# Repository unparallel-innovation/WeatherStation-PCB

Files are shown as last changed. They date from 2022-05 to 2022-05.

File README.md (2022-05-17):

[][cc-by-nc-sa]

This work is licensed under a
[Creative Commons Attribution-NonCommercial-ShareAlike 4.0 International License][cc-by-nc-sa].

[][cc-by-nc-sa]

[cc-by-nc-sa]: http://creativecommons.org/licenses/by-nc-sa/4.0/
[cc-by-nc-sa-image]: https://licensebuttons.net/l/by-nc-sa/4.0/88x31.png
[cc-by-nc-sa-shield]: https://img.shields.io/badge/License-CC%20BY--NC--SA%204.0-lightgrey.svg

# Unparallel Weather Station PCB

The Weather Station PCB is a board that together with, Software and 3D case allows anyone to build their low-cost weather station. The Weather Station PCB was made open source, so we are sharing in this repository the custom PCB design (Eagle and Gerbers files) and other information, as the BOM and item lists. The software for the weather station is also open-source and can be used as is, or freely customized to meet your own needs and requirements. A model for printing a 3D case for your weather station is also provided (both in other repositories).  

WeatherStation_3D_2202

The Weather Station PCB using low-cost hardware and a LoPy4 board. The LoPy4 board is equipped with several connectivity options (e.g. Sigfox, LoRa, Wi-Fi and Bluetooth). Currently, the weather station uses Sigfox and/or Wi-Fi to send the data to the cloud, however, the software can be extended to support other connectivity options. A Grafana dashboard is then used to display the historical weather data that is stored on the cloud.

The weather station uses an external sensor (AM2315) for reading temperature and relative humidity, a weather meter kit (SEN-15901) for wind speed, wind direction and precipitation. The weather station is powered from a Li-Ion battery that is charged with a photovoltaic panel which is also used to measure solar radiation. Due to the system’s low-power operation and solar energy harvesting features, it is energy autonomous and can be deployed in remote places.

Note: the custom Weather Station PCB may be ordered via [PCBWay shared project link](https://www.pcbway.com/project/shareproject/Unparallel_Weather_Station_PCB.html).

#### Measured parameters:
*	Temperature (ºC)
*	Relative Humidity (%)
*	Rainfall (mm/h)
*	Wind Speed (km/h)
*	Wind Gust Speed (km/h)
*	Wind Direction (degrees)
*	Wind Gust Direction (degrees)
*	Solar Radiation (W/m2)
*	Battery Voltage (V)

#### Components:
*	[LoPy 4.0](https://pycom.io/product/lopy4/)
* [Unparallel WeatherStation PCB](https://www.pcbway.com/project/shareproject/Unparallel_Weather_Station_PCB.html)
*	[Unparallel WeatherStation Enclosure](https://github.com/unparallel-innovation/WeatherStation-Enclosure)
*	[Encased I2C Temperature/Humidity Sensor - AM2315](https://www.adafruit.com/product/1293)
*	[Weather Meter Kit - SEN-15901](https://www.sparkfun.com/products/15901)
*	[Li-Ion battery (3.65V - 8000mAh)](https://www.tme.eu/en/details/cl-18650-29e_1s3p/rechargeable-batteries/cellevia-batteries/)
*	[Solar Panel (2.5W - 116x160mm)](https://www.seeedstudio.com/2-5W-Solar-Panel-116X160.html)
*	[Sigfox Antenna Kit (868MHz)](https://pycom.io/product/lora-868mhz-915mhz-sigfox-antenna-kit/)
* [Expansion Board 3.0](https://pycom.io/product/expansion-board-3-0/)

## Related Repositories:
*	[Unparallel WeatherStation Enclosure](https://github.com/unparallel-innovation/WeatherStation-Enclosure)
*	[Unparallel WeatherStation Documentation](https://github.com/unparallel-innovation/WeatherStation-Documentation)
*	[Unparallel WeatherStation Software](https://github.com/unparallel-innovation/WeatherStation-Software)
*	[Unparallel WeatherStation Connector](https://github.com/unparallel-innovation/WeatherStation-Connector)

###### This work was done in the context of SmartAgriHubs Research Project, which has received funding from the European Union’s Horizon 2020 research and innovation programme under grant agreement No 818182

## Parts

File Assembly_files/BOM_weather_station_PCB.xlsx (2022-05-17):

Item # | Schematic Reference | Qty per brd | Value | Package | Manufacturer Part Number (MPN) | MFR | Description | Type | Notes
1 | C1 C2 | 2 | 10n | C0603 | 885012206089 | Wurth Elektronik | CAP MLCC - SMD/SMT WCAP-CSGP 0.01uF 0603 10% 50V | SMD
2 | C3 | 1 | 220n | C0603 | CC0603KRX7R7BB224 | YAGEO | CAP MLCC - SMD/SMT 16V 0.22uF X7R 0603 10% | SMD
3 | C4 C9 C13 | 3 | 100n | C0603 | CC0603KRX7R8BB104 | YAGEO | CAP MLCC - SMD/SMT 0603 25V 0.1uF X7R 0603 10% | SMD
4 | C5 C6 C7 C10 | 4 | 1u | C0805 | C0805C105K3RACTU | KEMET | CAP MLCC - SMD/SMT 25V 1uF X7R 0805 10% | SMD
5 | C8 | 1 | 4u7 | C0805 | GRM21BZ7YA475KE15L | Murata | CAP MLCC - SMD/SMT 35V 4.7uF X7R 0805 10% | SMD | Alternative: C0805C475K4RACAUTO
6 | CN1 | 1 | S2B-PH-SM4 | JST_2PIN-SMT-RA | S2B-PH-SM4-TB(LF)(SN) | JST | SOCKET Male; PH; 2mm; PIN: 2; SMT | SMD | Alternative: B2B-PH-SM4-TB (pins aligned to the outside of the board)
7 | D1 D2 D4 D5 D6 D7 D8 D12 | 8 | SS14L | SUB_SMA | SS14L | Taiwan Semiconductor | Schottky Rectifiers 1A 40V Sub SMA-2 | SMD
8 | D11 Or D9 | 1 | CZRB5339B-HF | DO-214AA-2 OR DO-15-2 | CZRB5339B-HF Or 1N5339B-TP | Comchip Technology Or Micro Commercial Components (MCC) | Zener Diodes 5W 5.6V SMB DO-214AA-2 Or Zener Diodes 5.0W 5.6V 1uA 865mA 13.4A DO-15-2 | SMD Or THT | If has problem to buy the D11 item, can you buy the D9 item D11 Alternative: SMBJ5339B-TP
9 | D3 D10 | 2 | RFN2LAM4STFTR | SOD-128 | RFN2LAM4STFTR | ROHM Semiconductor | Diodes 400V VR 1.5A IO SOD-128; PMDTM | SMD
10 | F1 F2 | 2 | 0ZCK0075FF2E | PTC-0805 | 0ZCK0075FF2E | Bel | Resettable Fuses - PPTC Hold current 750 mA 0805 | SMD
11 | J1 J2 | 2 | RJ11 | RJ11-6 | 95501-2661 | Molex | Ethernet Connectors RA 6/6 RJ12 LOW PROFILE THT | THT | Alternative: 54601-906WPLF
12 | JP3 JP4 | 2 | 14POS 2.54mm | LOPY4_SHIELD | DS1023-1*14S21 | CONNFLY | CONN Female; PIN: 14; straight; 2.54mm; THT; 1x14; 3A | THT
13 | JP5 | 1 | 6POS 2.54mm | PINHD-1X6 | DS1023-1*6S21 | CONNFLY | CONN Female; PIN: 6; straight; 2.54mm; THT; 1x6; 3A | THT
14 | JP7 JP8 JP9 JP10 | 4 | Block 1x2 5mm | W237-102 | DG300-5.0-2P12 | DEGSON ELECTRONICS | PCB terminal block; angled 90°; 5mm; ways: 2; on PCBs; 2.5mm2; 24A | THT | Alternative: EBBA-02-C-SS-BU
15 | LED1 | 1 | Green_LED | LED0805 | LG R971-KN-1 | Osram Opto Semiconductor | Standard LEDs - SMD 0805 Green, 570nm 26mcd, 20mA | SMD | Cathode has a mark (".") Alternative: LTST-C170KGKT
16 | Q1 Q3 Q9 | 3 | SI2333DDS | SOT-23-3 | SI2333DDS-T1-GE3 | Vishay | Transistor: P-MOSFET; unipolar; -12V; -5.2A; Idm: -20A; 1.1W; SOT-23-3 | SMD | Alternative: DMG2305UX
17 | Q2 Q5 Q6 | 3 | BSS138 | SOT-23-3 | BSS138-7-F | Diodes Incorporated | MOSFET 300mW 50V DSS SOT-23-3 N-channel | SMD
18 | R1 R2 R3 R5 R6 R7 R18 | 7 | 1k | R0603 | CR0603-FX-1001ELF | Bourns | RES Thick Film Resistors - SMD 0603 1K 1% 1/10W | SMD
19 | R10 | 1 | 200m | R0805 | RL1220S-R20-F | Susumu | RES Current Sense Resistors - SMD 0805 1/3W 0.20ohm 1% | SMD | Alternative: KDV08FR200ET
20 | R11 R12 | 2 | 10R | R0603 | CRCW060310R0FKEAC | Vishay | RES Thick Film Resistors - SMD 0603 1/10Watt 10ohms 1% Commercial Use | SMD
21 | R13 R22 R27 R33 | 4 | 47k | R0603 | RC0603FR-0747KL | YAGEO | RES Thick Film Resistors - SMD 47 kOhms 100mW 0603 1% | SMD
22 | R14 R15 R26 R39 | 4 | 10k | R0603 | CR0603-FX-1002ELF | Bourns | RES Thick Film Resistors - SMD 0603 10K 1% 1/10W | SMD
23 | R16 R37 R40 | 3 | 0R | R0603 | CR0603-J/-000ELF | Bourns | RES Thick Film Resistors - SMD 0 ohm Jumper 0603 | SMD | Soldering RES jumper (or Shunt)
24 | R19 R20 R30 | 3 | 100k | R0603 | RC0603FR-07100KL | YAGEO | RES Thick Film Resistors - SMD 0603 100 kOhms 100mW 0603 1% | SMD
25 | R23 R25 R36 | 3 | 200k | R0603 | CRCW0603200KFKEAC | Vishay | RES Thick Film Resistors - SMD 0603 1/10Watt 200Kohms 1% | SMD
26 | R29 | 1 | 2k74 | R0603 | RC0603FR-132K74L | YAGEO | RES Thick Film Resistors - SMD 0603 2.74kOhms 1/10W 0603 1% | SMD
27 | R4 | 1 | 4k7 | R0603 | RC0603FR-074K7L | YAGEO | RES Thick Film Resistors - SMD 4.7 kOhms 100mW 0603 1% | SMD
28 | R8 | 1 | 22k | R0603 | RC0603FR-0722KL | YAGEO | RES Thick Film Resistors - SMD 22 kOhms 100mW 0603 1% | SMD
29 | R9 R24 | 2 | 499k | R0603 | CR0603-FX-4993ELF | Bourns | RES Thick Film Resistors - SMD 499K ohm 0603 1% | SMD
30 | U1 | 1 | INA219BIDCN | SOT-23-8 | INA219BIDCN | Texas Instruments | IC Current & Power Monitors & Regulators 0-Drift,Bi-dir Current/Pwr Monitor SOT-23-8 | SMD
31 | U2 | 1 | MCP73831T | SOT23-5 | MCP73831T-2ACI/OT | Microchip | IC Battery Management Charge LI-ION 1CEL | SMD
32 | U3 | 1 | SN74AUP2G14DCKR | SC70-6 | SN74AUP2G14DCKR | Texas Instruments | IC Inverters Lo-Pwr Dual Schmitt- Trigger Inverter SC70-6 | SMD

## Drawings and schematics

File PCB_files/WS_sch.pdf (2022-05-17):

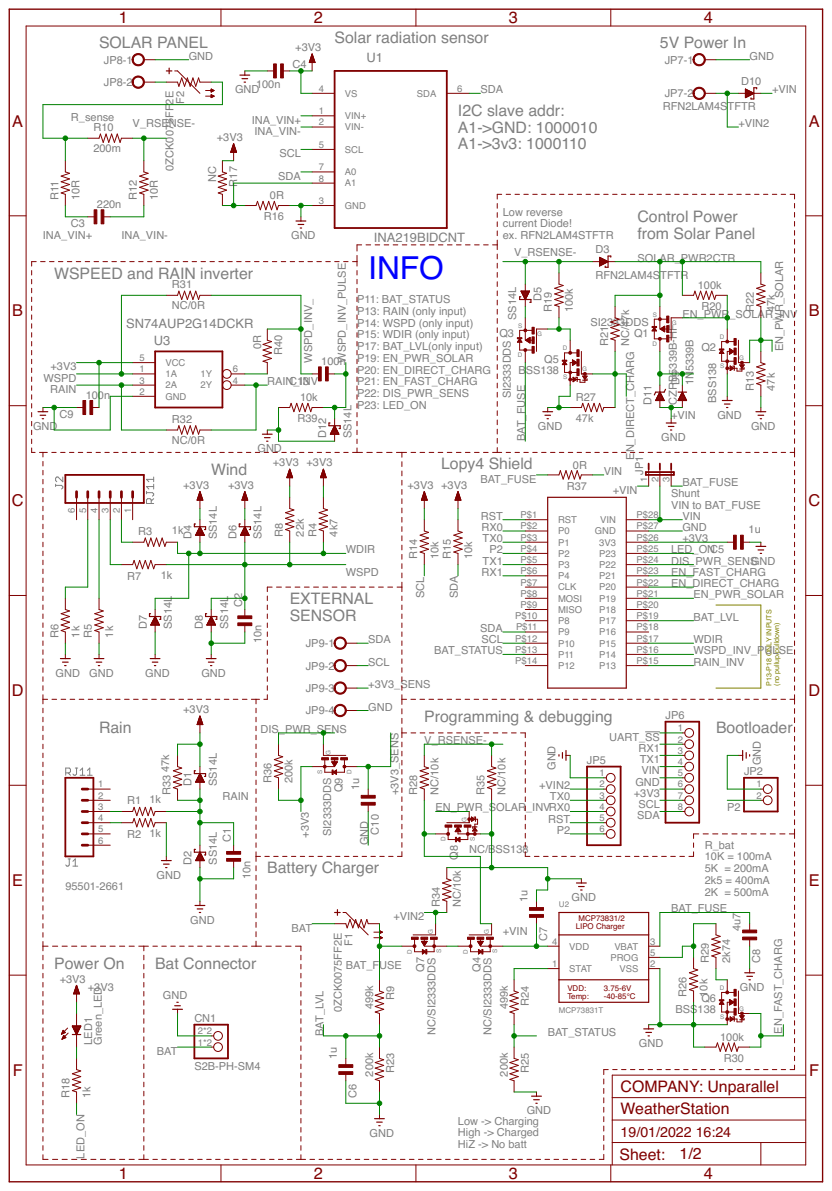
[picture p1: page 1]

WSPEED and RAIN inverter

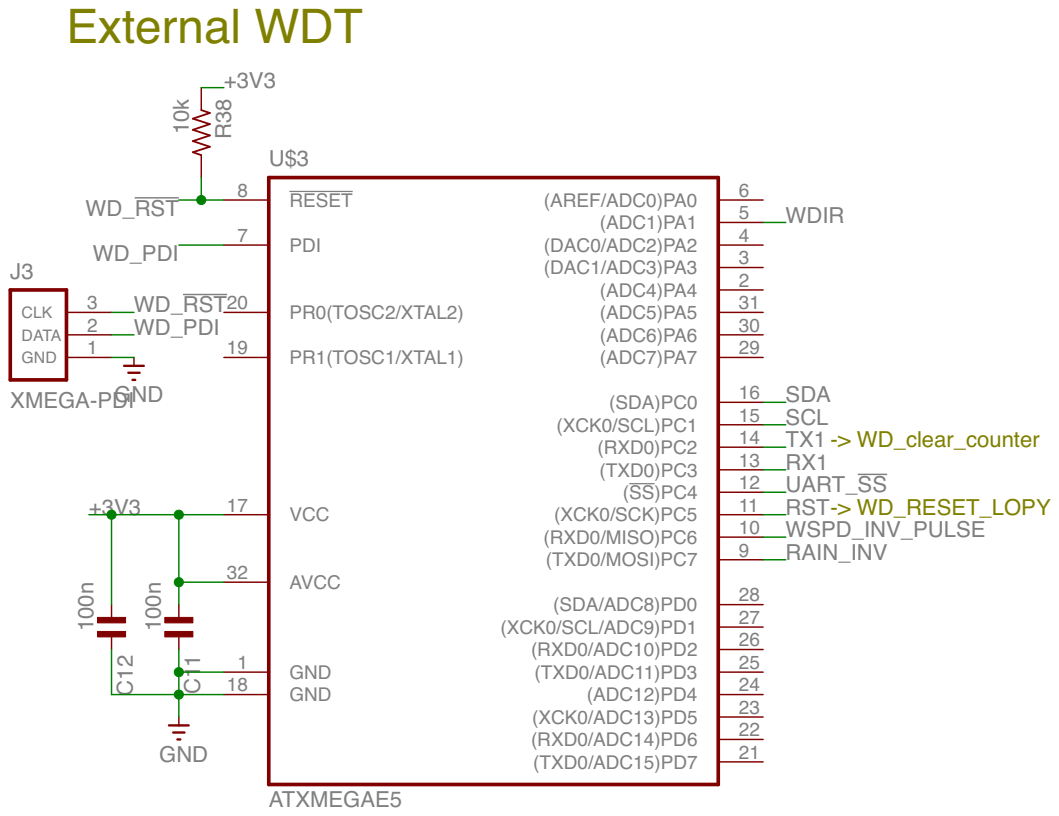
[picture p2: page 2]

External WDT | +3V3

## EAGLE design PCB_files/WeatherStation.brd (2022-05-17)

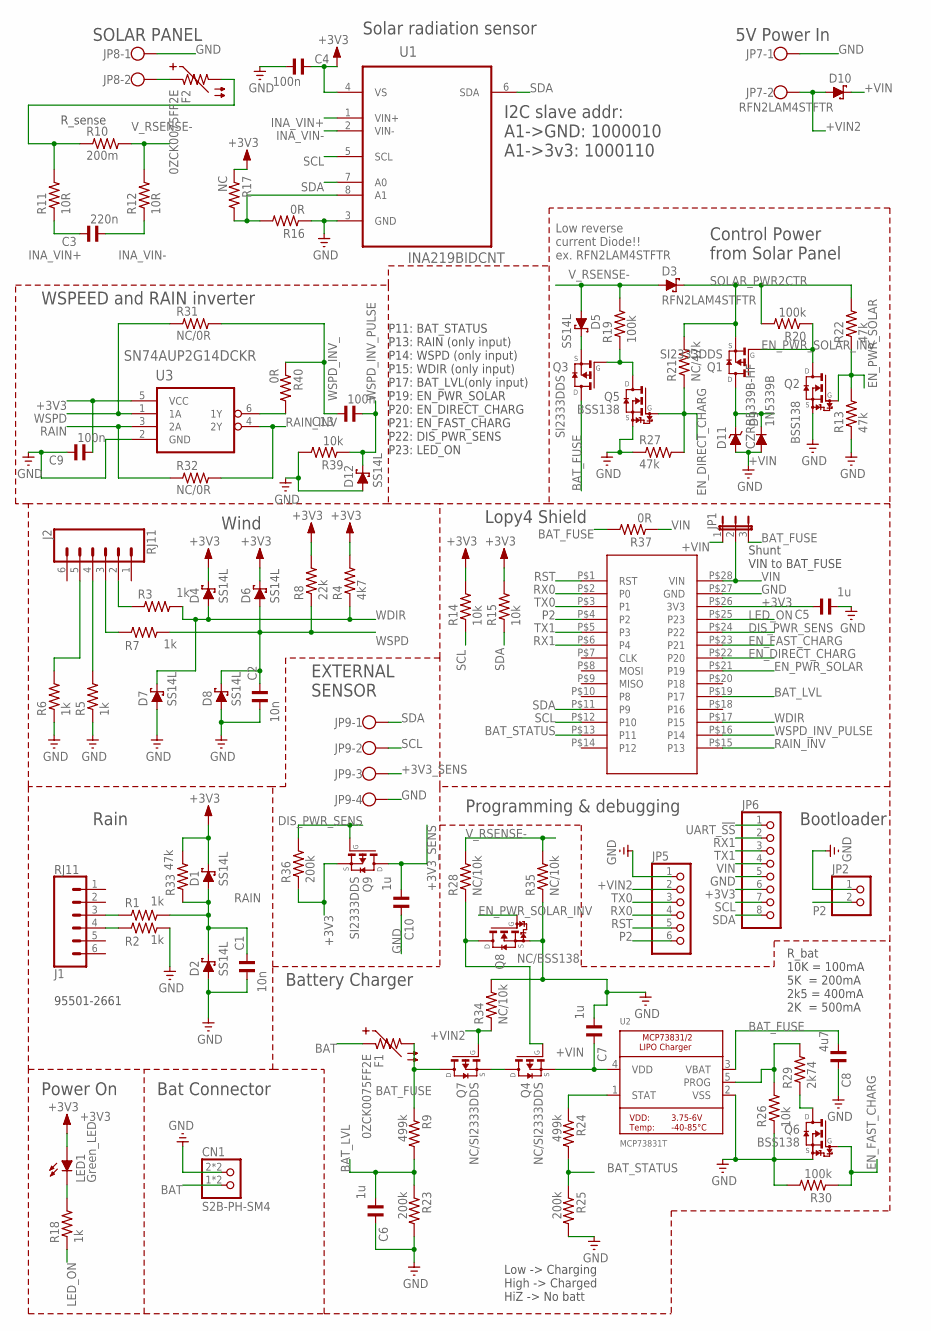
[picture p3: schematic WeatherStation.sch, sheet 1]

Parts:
C1, C2: 10n; C0603/C0805_PROTO_SLIM
C3: 220n; C0603
C4, C9, C13: 100n; C0603
C5, C6, C7, C10: 1u; C0603/C0805_PROTO_SLIM
C8: 4u7; C0603/C0805_PROTO_SLIM
CN1: S2B-PH-SM4; JST-PH-2-SMT-RA_OK
D1, D2, D4, D5, D6, D7, D8, D12: SS14L; SUB_SMA_PROTO
D3, D10: RFN2LAM4STFTR; SMA_SOD-128_PROTO
D9: 1N5339B; DO15-12
D11: CZRB5339B-HF; SMB_PROTO
F1, F2: 0ZCK0075FF2E; R0603/R0805_PROTO_SLIM
J1, J2: RJ11; RJ11-6
JP1: JP2E-0805; R0805/2
JP2: PINHD-1X2; 1X02
JP5: PINHD-1X6; 1X06
JP6: PINHD-1X8; 1X08
JP7, JP8: W237-102
JP9: W237-4
LED1: Green_LED; CHIP-LED0805
Q1, Q3, Q9: SI2333DDS; SOT23_PROTO_SLIM
Q2, Q5, Q6: BSS138; SOT23_PROTO_SLIM
Q4, Q7: NC/SI2333DDS; SOT23_PROTO_SLIM
Q8: NC/BSS138; SOT23_PROTO_SLIM
R1, R2, R3, R5, R6, R7, R18: 1k; R0603
R4: 4k7; R0603
R8: 22k; R0603
R9, R24: 499k; R0603/R0805_PROTO_SLIM
R10: 200m; R0603/R0805_PROTO_SLIM
R11, R12: 10R; R0603
R13, R22, R27, R33: 47k; R0603
R14, R15, R26, R39: 10k; R0603
R16, R37, R40: 0R; R0603
R17: NC; R0603
R19, R20, R30: 100k; R0603
R21: NC/47k; R0603
R23, R25, R36: 200k; R0603/R0805_PROTO_SLIM
R28, R34, R35: NC/10k; R0603
R29: 2k74; R0603/R0805_PROTO_SLIM
R31, R32: NC/0R; R0603
U1: INA219BIDCNT; SOT65P280X145-8N
U2: MCP73831T; SOT23-5
U3: SN74AUP2G14DCKR; SOT65P210X110-6N_EDIT
U$2: LOPY4_SHIELD

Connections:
+3V3: C4.1, C5.1, C9.2, D1.C, D4.C, D6.C, JP6.6, LED1.A, Q9.2 (S), R4.2, R8.2, R14.2, R15.2, R17.1, R33.2, R36.1, U1.4 (VS), U3.5 (VCC), U$2.P$26 (3V3); also elsewhere on the board
+3V3_SENS: C10.2, JP9.3, Q9.3 (D)
+VIN: C7.1, D9.C, D10.C, D11.C, JP1.1, Q1.3 (D), Q4.2 (S), U2.4 (VDD)
+VIN2: D10.A, JP5.2, JP7.2, Q7.1 (G), R34.1
BAT: CN1.1 (2), CN1.3 (2), F1.1
BAT_FUSE: C8.2, F1.2, JP1.3, Q3.3 (D), Q7.3 (D), R9.1, R37.2, U2.3 (VBAT)
BAT_LVL: C6.2, R9.2, R23.1, U$2.P$19 (P17)
BAT_STATUS: R24.2, R25.1, U$2.P$13 (P11)
DIS_PWR_SENS: Q9.1 (G), R36.2, U$2.P$24 (P22)
EN_DIRECT_CHARG: Q5.1 (G), R21.1, R27.2, U$2.P$22 (P20)
EN_FAST_CHARG: Q6.1 (G), R30.1, U$2.P$23 (P21)
EN_PWR_SOLAR: Q2.1 (G), R13.2, R22.1, U$2.P$21 (P19)
EN_PWR_SOLAR_INV: Q1.1 (G), Q2.3 (D), Q8.1 (G), R20.1
GND: C1.2, C2.2, C4.2, C5.2, C6.1, C7.2, C8.1, C9.1, C10.1, CN1.2 (1), CN1.4 (1), D2.A, D7.A, D8.A, D9.A, D11.A, D12.A, JP2.1, JP5.1, JP6.5, JP7.1, JP8.1, JP9.4, Q2.2 (S), Q5.2 (S), Q6.2 (S), Q8.2 (S), R2.2, R5.1, R6.1, R13.1, R16.1, R23.2, R25.2, R26.1, R27.1, R30.2, R34.2, R35.1, R39.2, U1.3 (GND), U2.2 (VSS), U3.2 (GND), U$2.P$27 (GND); also elsewhere on the board
INA_VIN+: C3.1, R11.1, U1.1 (VIN+)
INA_VIN-: C3.2, R12.1, U1.2 (VIN-)
LED_ON: R18.1, U$2.P$25 (P23)
unnamed: D5.C, Q3.2 (S)
unnamed: F2.1, JP8.2
unnamed: J1.4, R2.1
unnamed: J1.3, R1.1
unnamed: J2.2, R3.1
unnamed: J2.3, R7.1
unnamed: J2.4, R5.2
unnamed: J2.5, R6.2
unnamed: Q4.1 (G), Q8.3 (D), R28.1
unnamed: R26.2, R29.2, U2.5 (PROG)
unnamed: R16.2, R17.2, U1.8 (A1)
unnamed: LED1.C, R18.2
unnamed: Q6.3 (D), R29.1
unnamed: R40.2, U3.6 (1Y)
unnamed: Q3.1 (G), Q5.3 (D), R19.1
unnamed: R24.1, U2.1 (STAT)
unnamed: Q4.3 (D), Q7.2 (S)
P2: JP2.2, JP5.6, U$2.P$4 (P2)
RAIN: C1.1, D1.A, D2.C, R1.2, R32.1, R33.1, U3.3 (2A)
RAIN_INV: R32.2, U3.4 (2Y), U$2.P$15 (P13); also elsewhere on the board
RST: JP5.5, U$2.P$1 (RST); also elsewhere on the board
RX0: JP5.4, U$2.P$2 (P0)
RX1: JP6.2, U$2.P$6 (P4); also elsewhere on the board
SCL: JP6.7, JP9.2, R14.1, U1.5 (SCL), U$2.P$12 (P10); also elsewhere on the board
SDA: JP6.8, JP9.1, R15.1, U1.6 (SDA), U1.7 (A0), U$2.P$11 (P9); also elsewhere on the board
SOLAR_PWR2CTR: D3.C, Q1.2 (S), R20.2, R21.2, R22.2
TX0: JP5.3, U$2.P$3 (P1)
TX1: JP6.3, U$2.P$5 (P3); also elsewhere on the board
UART_!SS: JP6.1; also elsewhere on the board
VBUS_SOLAR: F2.2, R10.1, R11.2
VIN: JP1.2, JP6.4, R37.1, U$2.P$28 (VIN)
V_RSENSE-: D3.A, D5.A, R10.2, R12.2, R19.2, R28.2, R35.2
WDIR: D4.A, D7.C, R3.2, R4.1, U$2.P$17 (P15); also elsewhere on the board
WSPD: C2.1, D6.A, D8.C, R7.2, R8.1, R31.1, U3.1 (1A)
WSPD_INV_: C13.1, R31.2, R40.1
WSPD_INV_PULSE: C13.2, D12.C, R39.1, U$2.P$16 (P14); also elsewhere on the board

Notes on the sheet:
Lopy4 Shield
EXTERNAL SENSOR
SOLAR PANEL
Rain
Wind
Solar radiation sensor
I2C slave addr: A1->GND: 1000010 A1->3v3: 1000110
Power On
5V Power In
P11: BAT_STATUS P13: RAIN (only input) P14: WSPD (only input) P15: WDIR (only input) P17: BAT_LVL(only input) P19: EN_PWR_SOLAR P20: EN_DIRECT_CHARG P21: EN_FAST_CHARG P22: DIS_PWR_SENS P23: LED_ON
Programming & debugging
Control Power from Solar Panel
R_bat 10K = 100mA 5K = 200mA 2k5 = 400mA 2K = 500mA
Low -> Charging High -> Charged HiZ -> No batt
Battery Charger
Bootloader
R_sense
95501-2661
Low reverse current Diode!! ex. RFN2LAM4STFTR
WSPEED and RAIN inverter
Bat Connector
Shunt VIN to BAT_FUSE

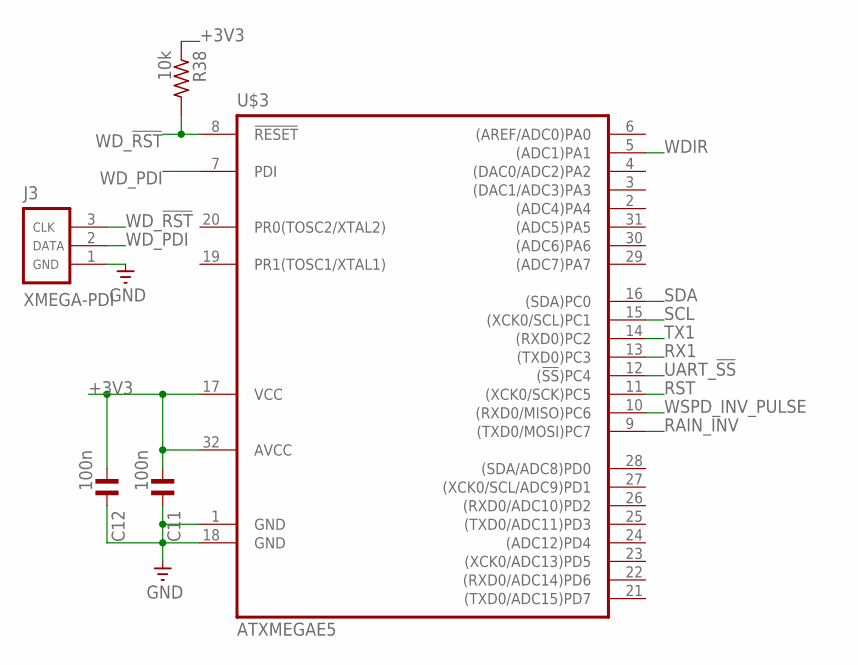
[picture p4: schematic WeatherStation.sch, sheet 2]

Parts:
C11, C12: 100n; C0603
J3: XMEGA-PDI; HDR-MA02-3P_P0.05_FABIO
R38: 10k; R0603
U$3: ATXMEGAE5; TQFP32_PROTO_SLIM

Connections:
+3V3: C11.2, C12.2, R38.1, U$3.17 (VCC), U$3.32 (AVCC); also elsewhere on the board
GND: C11.1, C12.1, J3.1, U$3.1 (GND), U$3.18 (GND); also elsewhere on the board
RAIN_INV: U$3.9 ((TXD0/MOSI)PC7); also elsewhere on the board
RST: U$3.11 ((XCK0/SCK)PC5); also elsewhere on the board
RX1: U$3.13 ((TXD0)PC3); also elsewhere on the board
SCL: U$3.15 ((XCK0/SCL)PC1); also elsewhere on the board
SDA: U$3.16 ((SDA)PC0); also elsewhere on the board
TX1: U$3.14 ((RXD0)PC2); also elsewhere on the board
UART_!SS: U$3.12 ((!SS!)PC4); also elsewhere on the board
WDIR: U$3.5 ((ADC1)PA1); also elsewhere on the board
WD_!RST: J3.3, R38.2, U$3.8 (!RESET!)
WD_PDI: J3.2, U$3.7 (PDI)
WSPD_INV_PULSE: U$3.10 ((RXD0/MISO)PC6); also elsewhere on the board

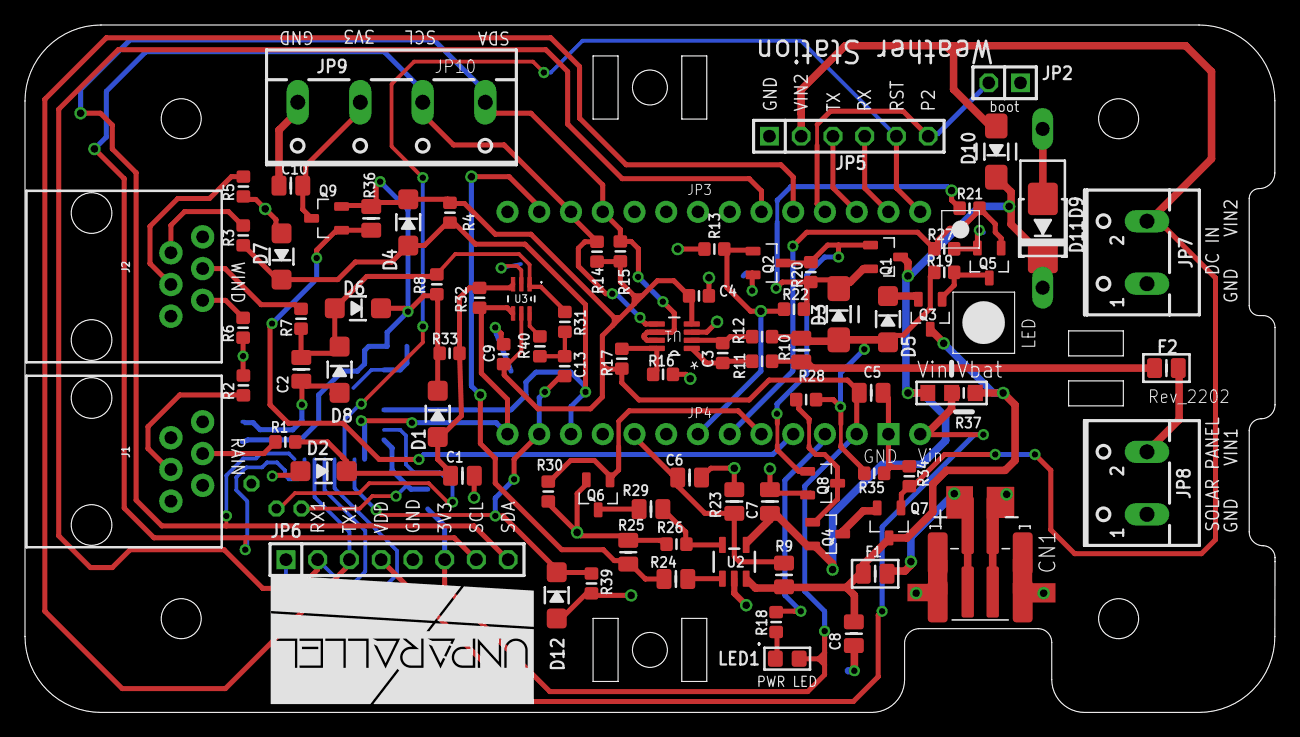
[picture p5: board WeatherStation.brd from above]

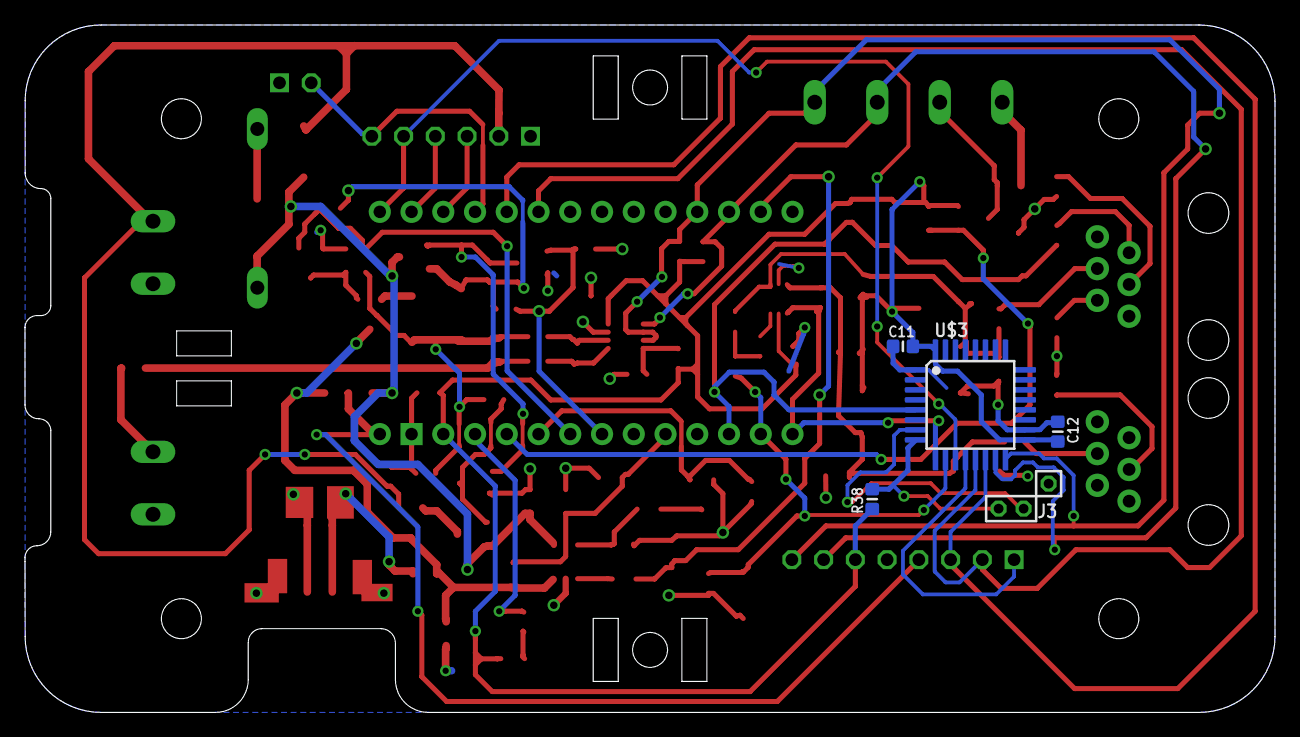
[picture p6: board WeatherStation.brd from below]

Board: 2 copper layers, 100.0 x 55.0 mm, 96 parts (5 on the bottom side), 55 nets.

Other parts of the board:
STAND2, STAND3: MOUNTHOLE_110MIL
U$1: UNPARALLEL_LOGO_NEW_0_INVERT_BIG

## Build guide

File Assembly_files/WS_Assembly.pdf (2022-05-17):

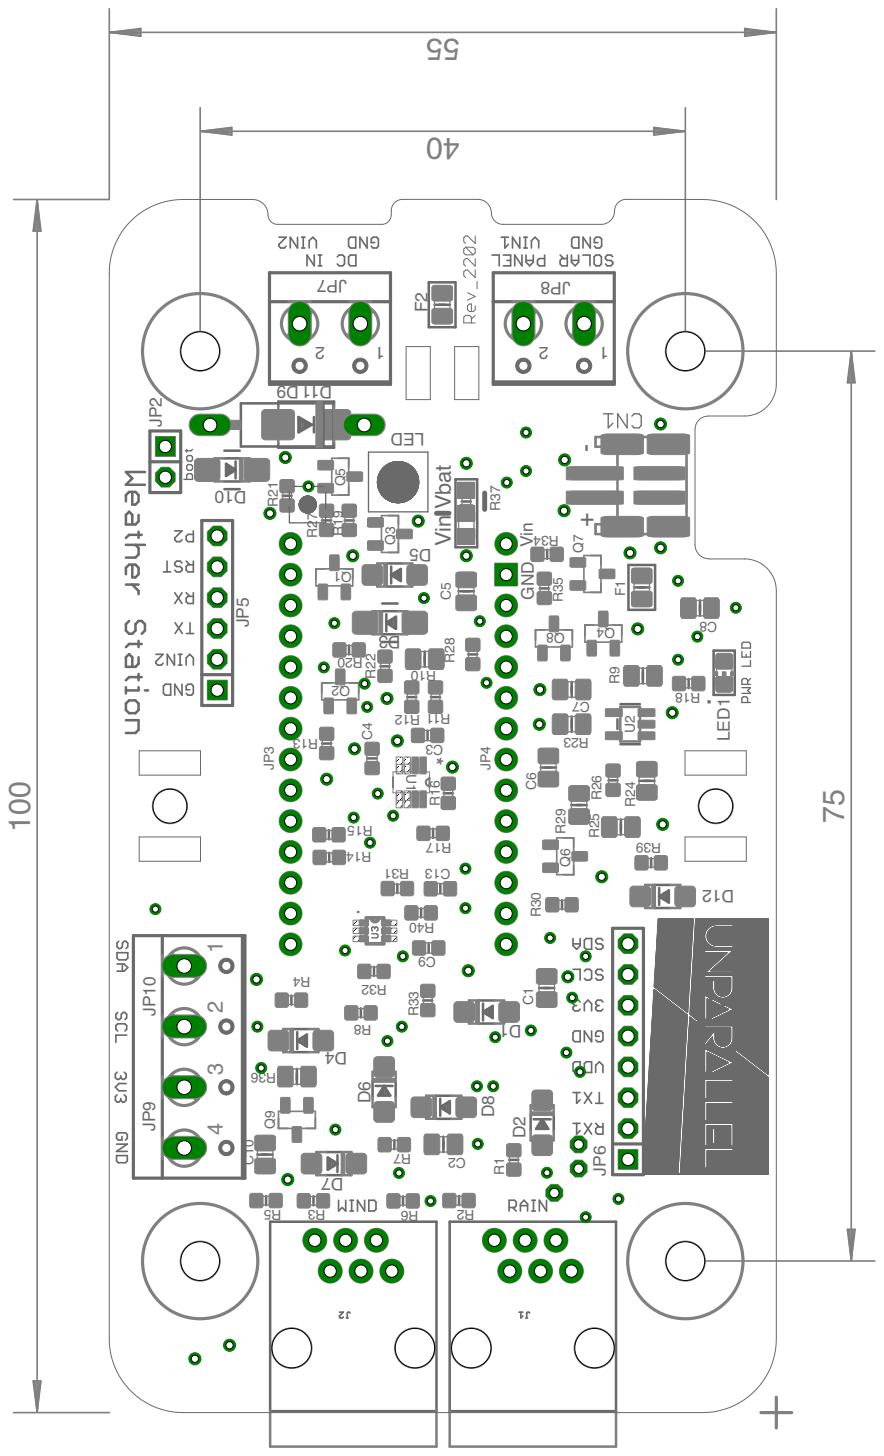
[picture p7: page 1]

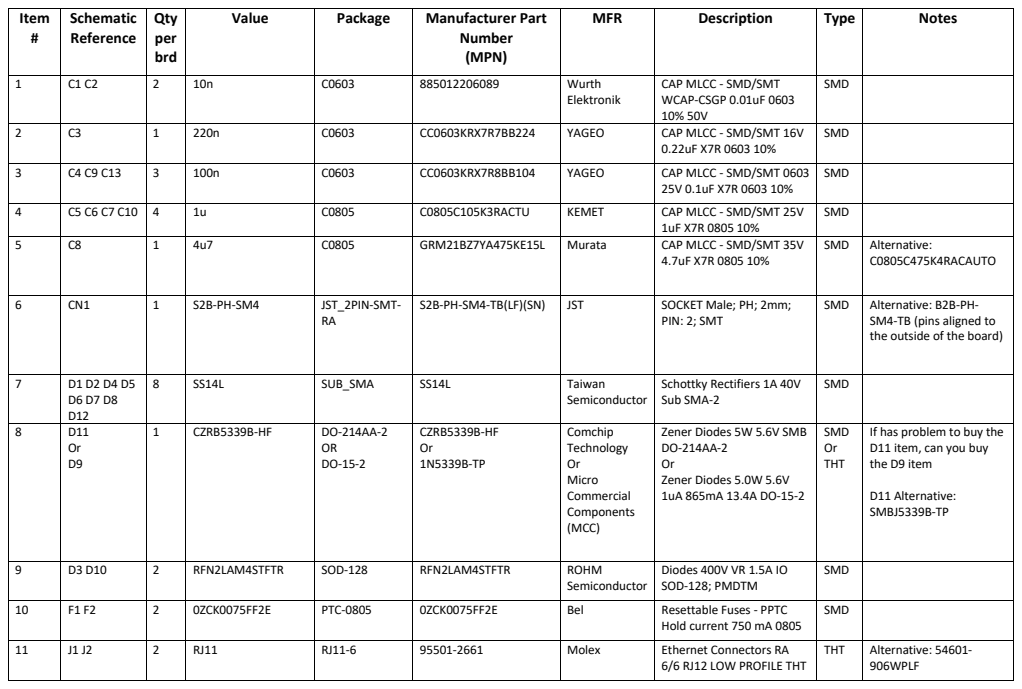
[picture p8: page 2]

Item # | Schematic Reference | Qty per brd | Value | Package | Manufacturer Part Number (MPN) | MFR | Description | Type | Notes

1 | C1 C2 | 2 | 10n | C0603 | 885012206089 | Wurth Elektronik | CAP MLCC - SMD/SMT WCAP-CSGP 0.01uF 0603 10% 50V | SMD

2 | C3 | 1 | 220n | C0603 | CC0603KRX7R7BB224 | YAGEO | CAP MLCC - SMD/SMT 16V 0.22uF X7R 0603 10% | SMD

3 | C4 C9 C13 | 3 | 100n | C0603 | CC0603KRX7R8BB104 | YAGEO | CAP MLCC - SMD/SMT 0603 25V 0.1uF X7R 0603 10% | SMD

4 | C5 C6 C7 C10 | 4 | 1u | C0805 | C0805C105K3RACTU | KEMET | CAP MLCC - SMD/SMT 25V 1uF X7R 0805 10% | SMD

5 | C8 | 1 | 4u7 | C0805 | GRM21BZ7YA475KE15L | Murata | CAP MLCC - SMD/SMT 35V 4.7uF X7R 0805 10% | SMD | Alternative: C0805C475K4RACAUTO

6 | CN1 | 1 | S2B-PH-SM4 | JST_2PIN-SMT-RA | S2B-PH-SM4-TB(LF)(SN) | JST | SOCKET Male; PH; 2mm; PIN: 2; SMT | SMD | Alternative: B2B-PH-SM4-TB (pins aligned to the outside of the board)

7 | D1 D2 D4 D5 D6 D7 D8 D12 | 8 | SS14L | SUB_SMA | SS14L | Taiwan Semiconductor | Schottky Rectifiers 1A 40V Sub SMA-2 | SMD

8 | D11 Or D9 | 1 | CZRB5339B-HF | DO-214AA-2 OR DO-15-2 | CZRB5339B-HF Or 1N5339B-TP | Comchip Technology Or Micro Commercial Components (MCC) | Zener Diodes 5W 5.6V SMB DO-214AA-2 Or Zener Diodes 5.0W 5.6V 1uA 865mA 13.4A DO-15-2 | SMD Or THT | If has problem to buy the D11 item, can you buy the D9 item D11 Alternative: SMBJ5339B-TP

9 | D3 D10 | 2 | RFN2LAM4STFTR | SOD-128 | RFN2LAM4STFTR | ROHM Semiconductor | Diodes 400V VR 1.5A IO SOD-128; PMDTM | SMD

10 | F1 F2 | 2 | 0ZCK0075FF2E | PTC-0805 | 0ZCK0075FF2E | Bel | Resettable Fuses - PPTC Hold current 750 mA 0805 | SMD

11 | J1 J2 | 2 | RJ11 | RJ11-6 | 95501-2661 | Molex | Ethernet Connectors RA 6/6 RJ12 LOW PROFILE THT | THT | Alternative: 54601-906WPLF

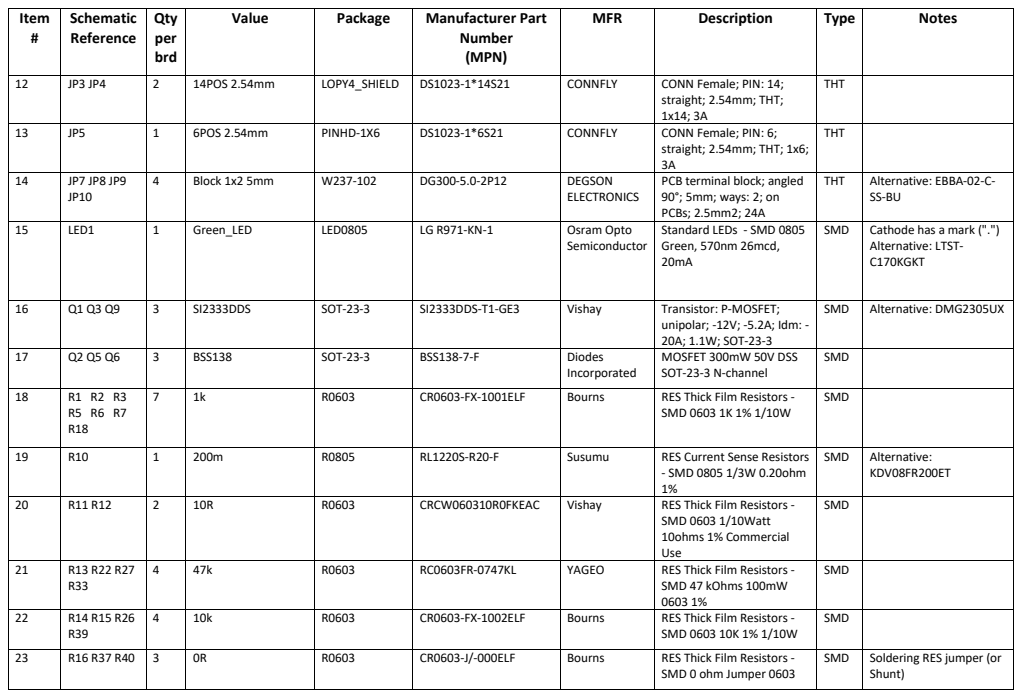
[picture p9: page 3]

# | Reference | per brd | | | Number (MPN)

12 | JP3 JP4 | 2 | 14POS 2.54mm | LOPY4_SHIELD | DS1023-1*14S21 | CONNFLY | CONN Female; PIN: 14; straight; 2.54mm; THT; 1x14; 3A | THT

13 | JP5 | 1 | 6POS 2.54mm | PINHD-1X6 | DS1023-1*6S21 | CONNFLY | CONN Female; PIN: 6; straight; 2.54mm; THT; 1x6; 3A | THT

14 | JP7 JP8 JP9 JP10 | 4 | Block 1x2 5mm | W237-102 | DG300-5.0-2P12 | DEGSON ELECTRONICS | PCB terminal block; angled 90°; 5mm; ways: 2; on PCBs; 2.5mm2; 24A | THT | Alternative: EBBA-02-C-SS-BU

15 | LED1 | 1 | Green_LED | LED0805 | LG R971-KN-1 | Osram Opto Semiconductor | Standard LEDs - SMD 0805 Green, 570nm 26mcd, 20mA | SMD | Cathode has a mark (".") Alternative: LTST-C170KGKT

16 | Q1 Q3 Q9 | 3 | SI2333DDS | SOT-23-3 | SI2333DDS-T1-GE3 | Vishay | Transistor: P-MOSFET; unipolar; -12V; -5.2A; Idm: -20A; 1.1W; SOT-23-3 | SMD | Alternative: DMG2305UX

17 | Q2 Q5 Q6 | 3 | BSS138 | SOT-23-3 | BSS138-7-F | Diodes Incorporated | MOSFET 300mW 50V DSS SOT-23-3 N-channel | SMD

18 | R1 R2 R3 R5 R6 R7 R18 | 7 | 1k | R0603 | CR0603-FX-1001ELF | Bourns | RES Thick Film Resistors -SMD 0603 1K 1% 1/10W | SMD

19 | R10 | 1 | 200m | R0805 | RL1220S-R20-F | Susumu | RES Current Sense Resistors - SMD 0805 1/3W 0.20ohm 1% | SMD | Alternative: KDV08FR200ET

20 | R11 R12 | 2 | 10R | R0603 | CRCW060310R0FKEAC | Vishay | RES Thick Film Resistors -SMD 0603 1/10Watt 10ohms 1% Commercial Use | SMD

21 | R13 R22 R27 R33 | 4 | 47k | R0603 | RC0603FR-0747KL | YAGEO | RES Thick Film Resistors -SMD 47 kOhms 100mW 0603 1% | SMD

22 | R14 R15 R26 R39 | 4 | 10k | R0603 | CR0603-FX-1002ELF | Bourns | RES Thick Film Resistors -SMD 0603 10K 1% 1/10W | SMD

23 | R16 R37 R40 | 3 | 0R | R0603 | CR0603-J/-000ELF | Bourns | RES Thick Film Resistors -SMD 0 ohm Jumper 0603 | SMD | Soldering RES jumper (or Shunt)

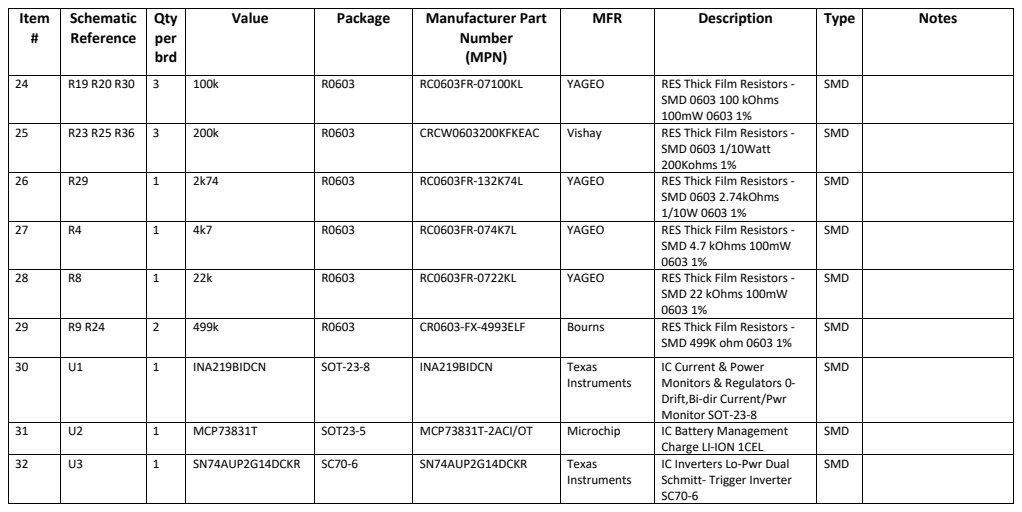
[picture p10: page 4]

# | Reference | per brd | | | Number (MPN)

24 | R19 R20 R30 | 3 | 100k | R0603 | RC0603FR-07100KL | YAGEO | RES Thick Film Resistors -SMD 0603 100 kOhms 100mW 0603 1% | SMD

25 | R23 R25 R36 | 3 | 200k | R0603 | CRCW0603200KFKEAC | Vishay | RES Thick Film Resistors -SMD 0603 1/10Watt 200Kohms 1% | SMD

26 | R29 | 1 | 2k74 | R0603 | RC0603FR-132K74L | YAGEO | RES Thick Film Resistors -SMD 0603 2.74kOhms 1/10W 0603 1% | SMD

27 | R4 | 1 | 4k7 | R0603 | RC0603FR-074K7L | YAGEO | RES Thick Film Resistors -SMD 4.7 kOhms 100mW 0603 1% | SMD

28 | R8 | 1 | 22k | R0603 | RC0603FR-0722KL | YAGEO | RES Thick Film Resistors -SMD 22 kOhms 100mW 0603 1% | SMD

29 | R9 R24 | 2 | 499k | R0603 | CR0603-FX-4993ELF | Bourns | RES Thick Film Resistors -SMD 499K ohm 0603 1% | SMD

30 | U1 | 1 | INA219BIDCN | SOT-23-8 | INA219BIDCN | Texas Instruments | IC Current & Power Monitors & Regulators 0-Drift,Bi-dir Current/Pwr Monitor SOT-23-8 | SMD

31 | U2 | 1 | MCP73831T | SOT23-5 | MCP73831T-2ACI/OT | Microchip | IC Battery Management Charge LI-ION 1CEL | SMD

32 | U3 | 1 | SN74AUP2G14DCKR | SC70-6 | SN74AUP2G14DCKR | Texas Instruments | IC Inverters Lo-Pwr Dual Schmitt- Trigger Inverter SC70-6 | SMD

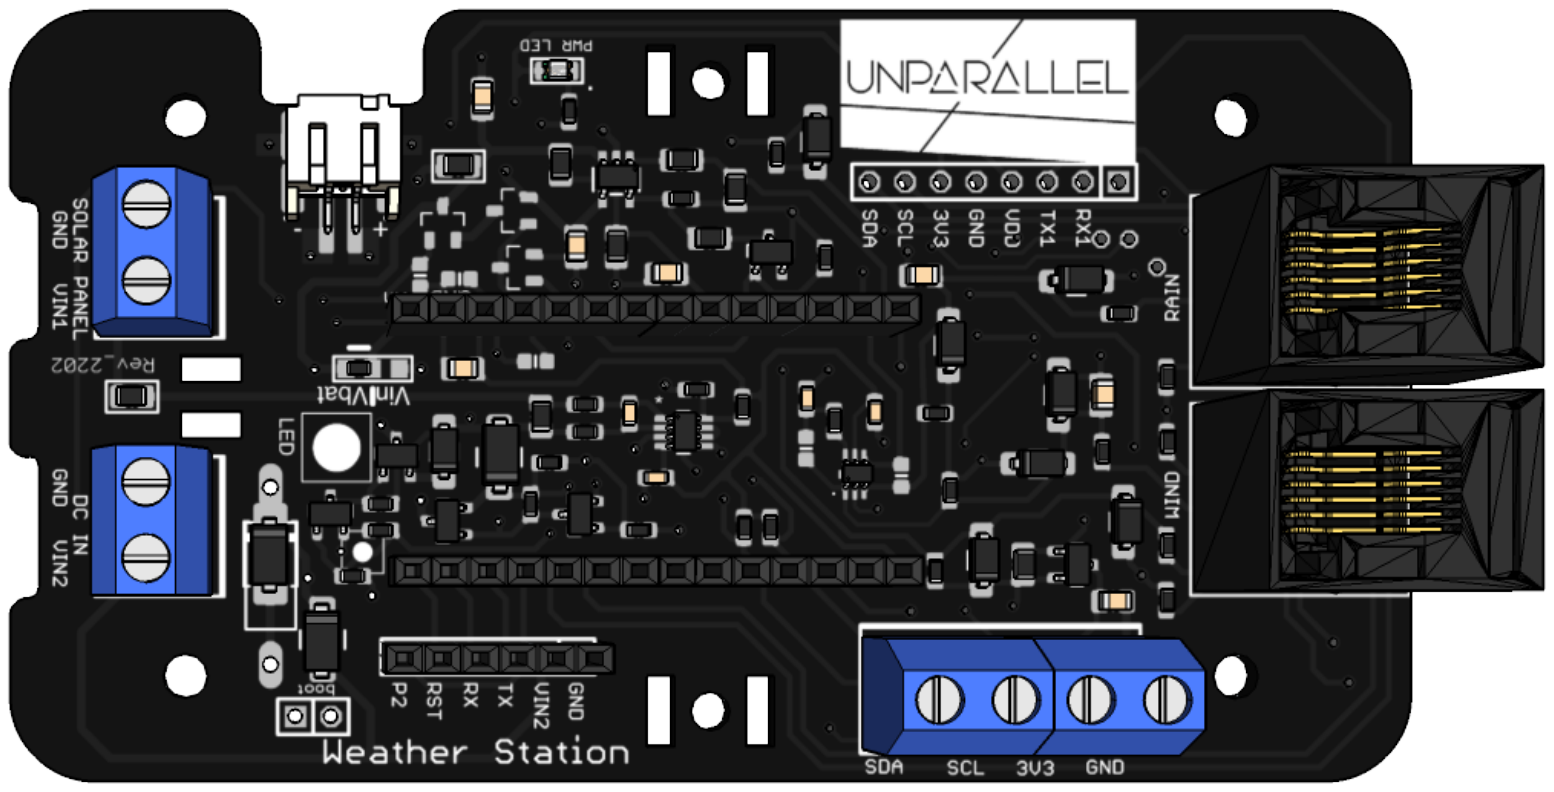
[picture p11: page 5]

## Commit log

2021-10-21 Update the repository structure; Update BOM list; Add/update assembly files; Add link in readme file
    [BOM_weather_station_PCB.xlsx, WeatherStation.brd, WeatherStation.sch]
2021-10-21 Update README.md
    Update WS pcb image
2022-05-17 Updated Weather Station files
    [BOM_weather_station_PCB.xlsx, WeatherStation.brd, WeatherStation.sch]

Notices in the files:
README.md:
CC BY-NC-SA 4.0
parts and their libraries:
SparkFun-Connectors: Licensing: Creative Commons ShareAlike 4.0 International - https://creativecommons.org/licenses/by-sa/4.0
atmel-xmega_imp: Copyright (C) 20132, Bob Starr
